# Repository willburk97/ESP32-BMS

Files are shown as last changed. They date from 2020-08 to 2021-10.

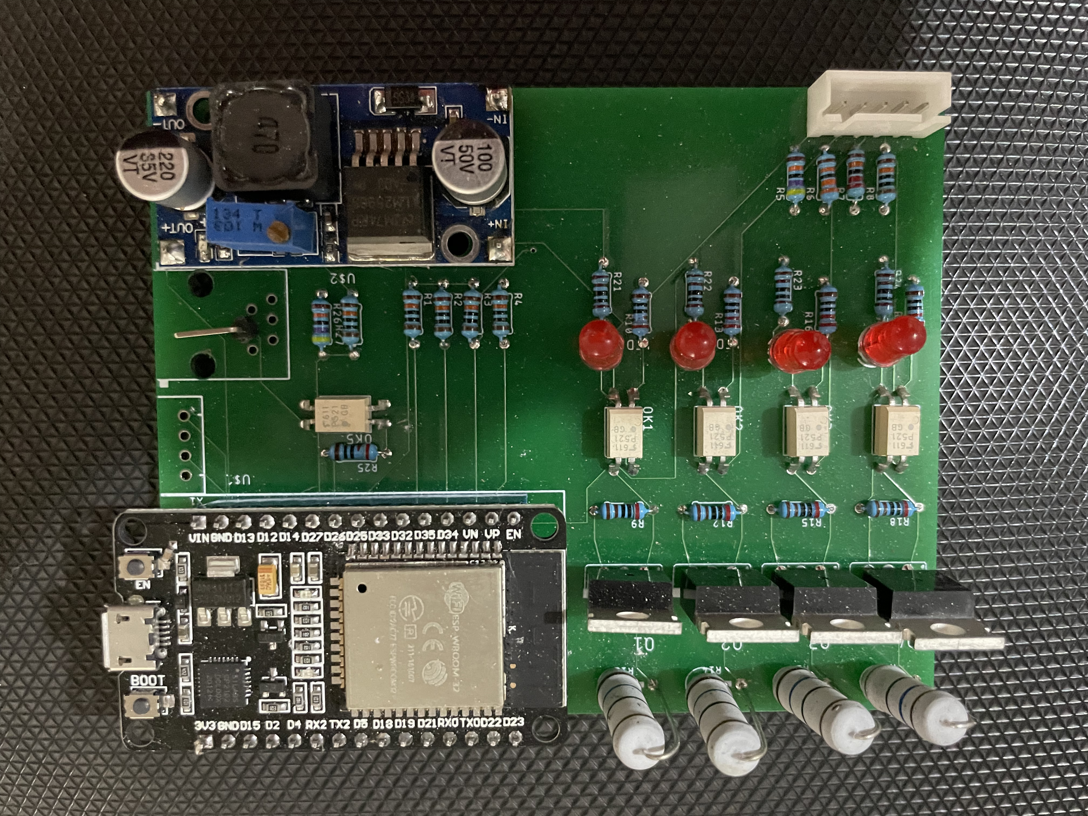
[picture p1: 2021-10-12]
7137F148-6C9B-44C9-9018-F6575CC51281.jpeg

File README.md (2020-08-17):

# ESP32-BMS
Single ESP32 monitoring and balancing multiple cell Li-Ion battery.

For each cell, to enable discharging, the ESP32 drives an opto-coupler (P521) with the digital output and the opto-coupler is driving the discharge mosfet(IRFZ44N) /resistor(16ohm,3W) across each cell. This'll be duplicatable across any number of cells (given the ESP32 has enough analog inputs and digital outputs. I'm using it for a 4 cell BMS/monitor which is using Adafruit io for trending/remote monitoring. The RJ11 port is to connect it to an Inverter. This is NOW coded in. I wasn't able to test the newer design with my old Kisae Inverter but the circuit in my original BMS worked fine (The single Arduino with a ESP8266-01 BMS).  

Note:  I added an I2C port to easily allow for adding components (like maybe an LCD/OLED display).

Ordered PCB and succesfully tested it (before I added the mounting holes and the wider traces.)   Worked great (didn't test i2c or rj11 port.)

My Kisae SW1220 inverter died in a lightning strike, but if you have one I think the schematic/board need to be changed to have Battery+ going to the optocoupler and the other leg going to the RJ11 port. (The wires on the opto-coupler will have to be reversed of course.)

My replacement inverter, a Go-Power GP-SW2000-12, has a remote input (Gnd, Enab, !Enab). I was able to use the schematic/board as is and simply connect the !Enab input on the inverter directly to the opto-coupler connection at the RJ11 port. (Which gets grounded when the digital output from the ESP32 turns on.)

Note: The Kisae inverter used a momentary Battery+ signal to turn the inverter on or off (change it from one state to the other).  The Go Power inverter requires a constant input signal (either battery+ or Gnd depending on the input you use) in order to be powered on. (Enab requires Batt+, !Enab requires Gnd, pick one to use.) The current code works with the Go Power Inverter.

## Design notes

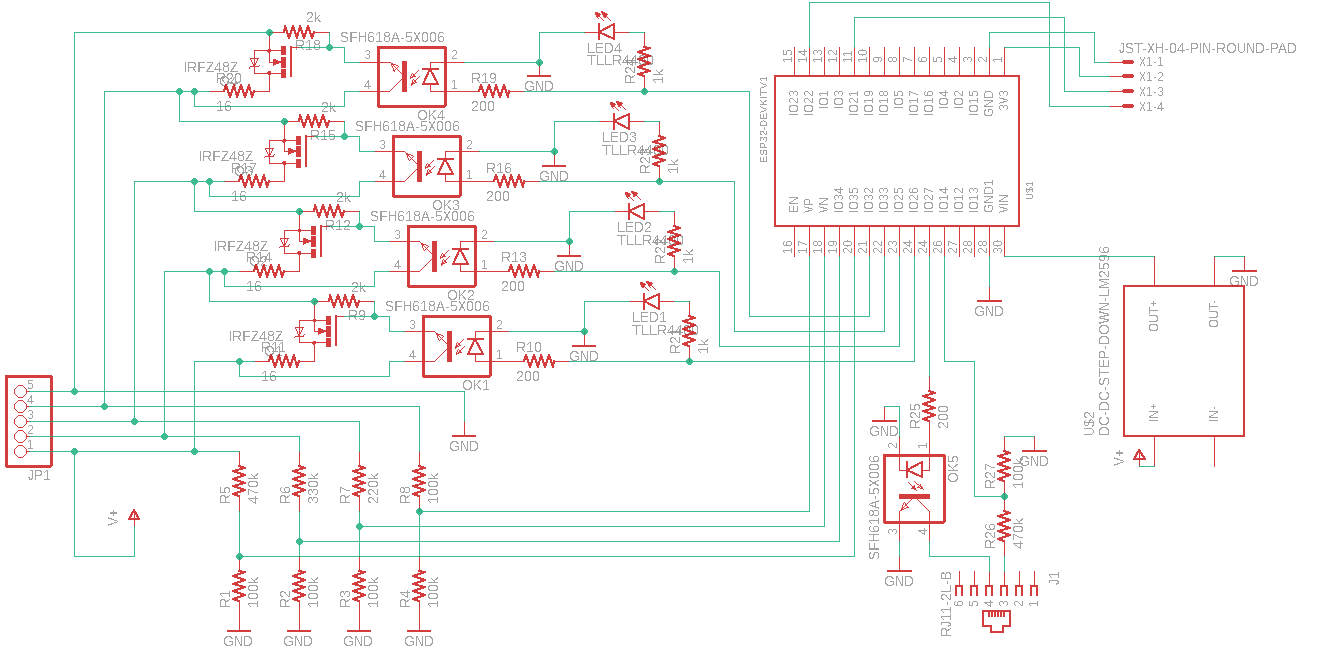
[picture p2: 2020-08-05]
FinalSchematic.png

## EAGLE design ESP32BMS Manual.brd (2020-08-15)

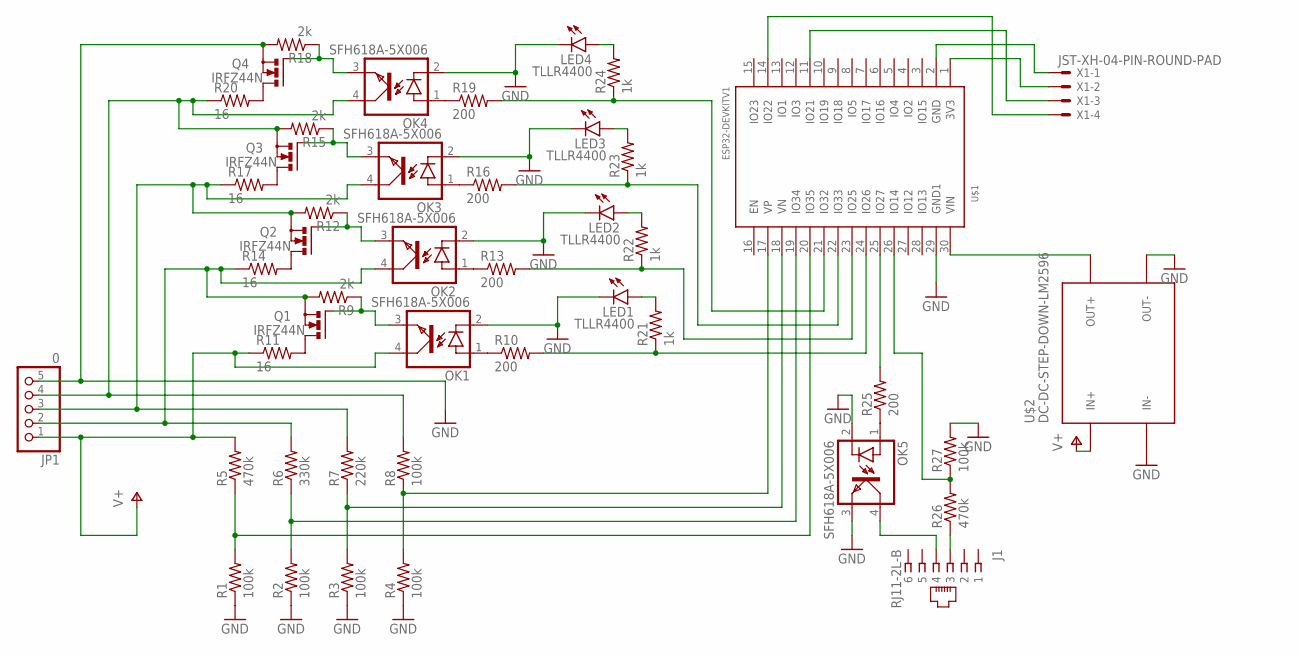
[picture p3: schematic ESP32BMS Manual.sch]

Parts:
J1: RJ11-2L-B; RJ11-NO_SHIELD
JP1: 0; 1X05
LED1, LED2, LED3, LED4: TLLR4400; LED3MM
OK1, OK2, OK3, OK4, OK5: SFH618A-5X006; DIP4-400
Q1, Q2, Q3, Q4: IRFZ44N; TO220BV
R1, R2, R3, R4, R8, R27: 100k; 0204/7
R5, R26: 470k; 0204/7
R6: 330k; 0204/7
R7: 220k; 0204/7
R9, R12, R15, R18: 2k; 0204/7
R10, R13, R16, R19, R25: 200; 0204/7
R11, R14, R17, R20: 16; 0414V
R21, R22, R23, R24: 1k; 0204/7
U$1: ESP32DEVKITV1; ESP32-DEVKITV1
U$2: DC-DC-STEP-DOWN-LM2596
X1: JST-XH-04-PIN-ROUND-PAD; JST-XH-04-PACKAGE-ROUND-PAD

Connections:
GND: JP1.5, LED1.K (C), LED2.K (C), LED3.K (C), LED4.K (C), OK1.2 (C), OK2.2 (C), OK3.2 (C), OK4.2 (C), OK5.2 (C), OK5.3 (EMIT), Q4.S, R1.1, R2.1, R3.1, R4.1, R18.2, R27.2, U$1.29 (GND1), U$2.IN-, U$2.OUT-
unnamed: R4.2, R8.1, U$1.17 (VP)
unnamed: R3.2, R7.1, U$1.18 (VN)
unnamed: R2.2, R6.1, U$1.19 (IO34)
unnamed: R1.2, R5.1, U$1.20 (IO35)
unnamed: LED1.A, R21.2
unnamed: JP1.2, OK2.4 (COL), Q1.S, R6.2, R9.2, R14.1
unnamed: JP1.3, OK3.4 (COL), Q2.S, R7.2, R12.2, R17.1
unnamed: JP1.4, OK4.4 (COL), Q3.S, R8.2, R15.2, R20.1
unnamed: OK1.1 (A), R10.1
unnamed: R19.2, R24.1, U$1.21 (IO32)
unnamed: OK2.1 (A), R13.1
unnamed: R16.2, R23.1, U$1.22 (IO33)
unnamed: R13.2, R22.1, U$1.23 (IO25)
unnamed: Q1.D, R11.2
unnamed: OK1.3 (EMIT), Q1.G, R9.1
unnamed: R10.2, R21.1, U$1.24 (IO26)
unnamed: Q2.D, R14.2
unnamed: OK2.3 (EMIT), Q2.G, R12.1
unnamed: U$1.30 (VIN), U$2.OUT+
unnamed: OK3.1 (A), R16.1
unnamed: LED2.A, R22.2
unnamed: Q3.D, R17.2
unnamed: OK3.3 (EMIT), Q3.G, R15.1
unnamed: LED3.A, R23.2
unnamed: OK4.1 (A), R19.1
unnamed: LED4.A, R24.2
unnamed: Q4.D, R20.2
unnamed: OK4.3 (EMIT), Q4.G, R18.1
unnamed: OK5.1 (A), R25.1
unnamed: R26.2, R27.1, U$1.26 (IO14)
unnamed: R25.2, U$1.25 (IO27)
unnamed: J1.3, R26.1
unnamed: J1.4, OK5.4 (COL)
unnamed: U$1.1 (3V3), X1.2
unnamed: U$1.2 (GND), X1.1
unnamed: U$1.11 (IO21), X1.3
unnamed: U$1.14 (IO22), X1.4
V+: JP1.1, OK1.4 (COL), R5.2, R11.1, U$2.IN+

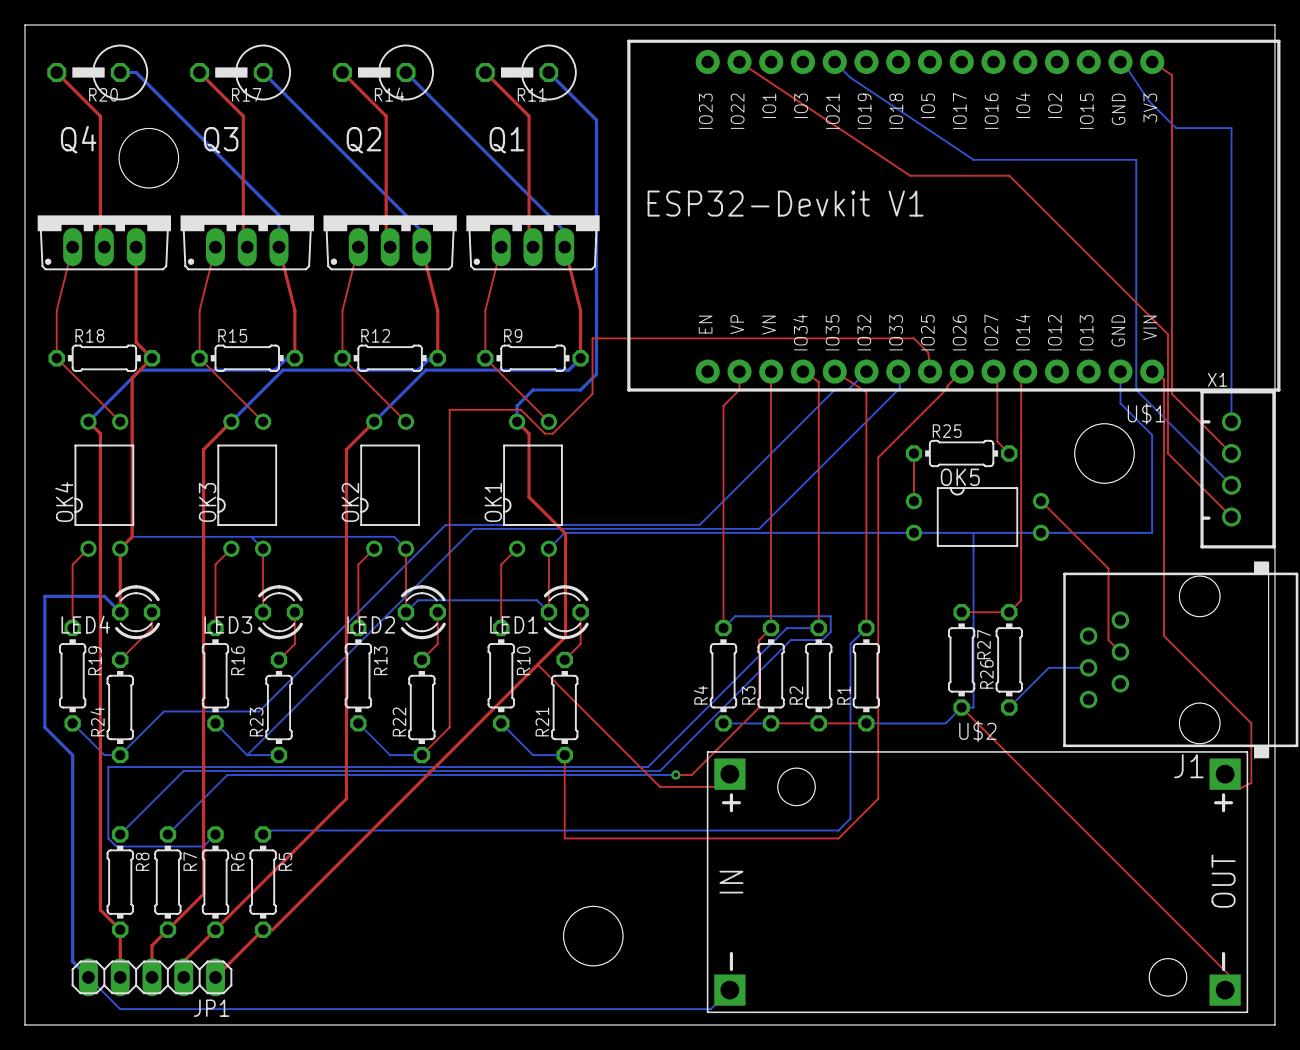
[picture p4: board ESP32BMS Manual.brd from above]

Board: 2 copper layers, 100.0 x 80.0 mm, 45 parts (0 on the bottom side), 39 nets.

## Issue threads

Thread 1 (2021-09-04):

Please include a screenshot of the board for people without PCB layout software installed

shodanx2, 2021-09-04:
It would explain a lot about how this works.

shodanx2, 2021-10-13:
These images should be easy to navigate to from the landing page (so readme file in your case)
They should specify which hardware version is depicted. Give them a version number even if they are the "final" version

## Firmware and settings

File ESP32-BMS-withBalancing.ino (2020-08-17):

// Tutorial Link: https://learn.adafruit.com/adafruit-io-basics-analog-input
//
// Adafruit invests time and resources providing this open source code.
// Please support Adafruit and open source hardware by purchasing
// products from Adafruit!
//
// Some written by Todd Treece for Adafruit Industries
// The rest written by William Burk for himself.
// Sorry Todd, for the mess.
// Copyright (c) 2016 Adafruit Industries
// Licensed under the MIT license.
//
// All text above must be included in any redistribution.


#define IO_USERNAME "NukeHunter"
#define IO_KEY "yourkeyhere"
#define WIFI_SSID "yourssidhere"
#define WIFI_PASS "yourpasswordhere"
#include "AdafruitIO_WiFi.h"
AdafruitIO_WiFi io(IO_USERNAME, IO_KEY, WIFI_SSID, WIFI_PASS);

#define LEDPin 2
#define inverterPin 27
int cell = 0;
int analogIn[] = {36, 39, 34, 35};
int dischargePin[] = {32, 33, 25, 26};
bool dischargeState[] = {false, false, false, false}; 
unsigned int sensorInt;
float sensorValue = 0;
float allowedCellDiff = 0.04;  /// 0.02 for big pack?
float lowBatt = 10;
unsigned long lastTxTime = 0;
unsigned int minTxTime = 60000;
//unsigned int sampleTime = 1000;
String debugText = "0.00 0.00 0.00 0.00 ";
//unsigned int dischargeTime[] = {0, 0, 0, 0};
int i;
float battVolt[4];
float cellVolt[4];
// bool inverterControl = false;  // not used yet

AdafruitIO_Feed *espbattery = io.feed("espbattery");
AdafruitIO_Feed *espbattery2 = io.feed("espbattery2");
AdafruitIO_Feed *espbattery3 = io.feed("espbattery3");
AdafruitIO_Feed *espbattery4 = io.feed("espbattery4");
//AdafruitIO_Feed *debugtext = io.feed("debug-text");
AdafruitIO_Feed *inverterstatus = io.feed("inverterstatus");
AdafruitIO_Feed *battdischarge1 = io.feed("battdischarge1");
AdafruitIO_Feed *battdischarge2 = io.feed("battdischarge2");
AdafruitIO_Feed *battdischarge3 = io.feed("battdischarge3");
AdafruitIO_Feed *battdischarge4 = io.feed("battdischarge4");
//AdafruitIO_Feed *battdischargetime4 = io.feed("battdischargetime4");
AdafruitIO_Feed *packvoltage = io.feed("packvoltage");

void setup() {
  pinMode(inverterPin, OUTPUT);
  pinMode(LEDPin, OUTPUT);
  analogSetClockDiv(20);
  for (cell=1;cell<5;cell++) {
    pinMode(dischargePin[cell-1], OUTPUT);
  }

  for (i=0;i<50;i=i+1) { analogRead(analogIn[1-1]); }  // Prevent first couple of reads from being anomalous.

  Serial.begin(115200);

  Serial.print("Connecting to Adafruit IO");
  io.connect();   // connect to io.adafruit.com

  while(io.status() < AIO_CONNECTED) {    // wait for a connection
    Serial.print(".");
    delay(500);
  }

  // we are connected
  Serial.println();
  Serial.println(io.statusText());

  inverterstatus->onMessage(inverterStatusChange);
  inverterstatus->get();
}

void loop() {
  io.run();

  updateVoltage();

  //Check for over discharged cell.
  for (cell=1;cell<5;cell++) {
    if (cellVolt[cell-1] < 2.5) {
      digitalWrite(dischargePin[cell-1], false);
      dischargeState[cell-1] = false;
      digitalWrite(inverterPin, false);
      inverterstatus->save(false);
      Serial.print("Battery "); Serial.print(cell); Serial.println(" Forced draining off...and inverter forced off.");
    }
  }

  
  // Blink to show sampling
  digitalWrite(LEDPin, HIGH); delay(30); digitalWrite(LEDPin, LOW);

  
// Do this every minute

  if(millis() > lastTxTime + minTxTime)
  {
    lastTxTime = millis();

    digitalWrite(LEDPin, HIGH);  // Long blink means transmitting and checking (non-balancing voltage)
    
    // Turn off discharging circuits.
    for (cell=1;cell<5;cell++) { 
      digitalWrite(dischargePin[cell-1], false);
    }

    delay(500); // Give cells time to settle.

    updateVoltage();

    // Get Low Cell Voltage
    lowBatt = 10; for (i=0;i<4;i++) { if (cellVolt[i] < lowBatt) { lowBatt = cellVolt[i]; } }
    Serial.print("Low Batt is at ");Serial.println(lowBatt);

    if (lowBatt > 3.5) { digitalWrite(inverterPin,true); }  // If battery has some juice, turn on the inverter.
  
    // Check for balance and turn on/off balancers
    for (cell=1;cell<5;cell++) {
  
      if ((cellVolt[cell-1] > (lowBatt + allowedCellDiff)) && (cellVolt[cell-1] > 3.0)) {
        digitalWrite(dischargePin[cell-1], true);
        dischargeState[cell-1] = true;
        Serial.print("Battery ");Serial.print(cell);Serial.println(" Draining");
      }
      else {
        digitalWrite(dischargePin[cell-1], false);
        dischargeState[cell-1] = false;
        Serial.print("Battery ");Serial.print(cell);Serial.println(" Not Draining");
      }

//      if (dischargeState[cell-1]) { dischargeTime[cell-1]++; } // Track minutes of discharging.

    }

    
    updateAdafruit();  // Here so we have accurate voltages as well as discharge status.
    
    digitalWrite(LEDPin, LOW);

  }

  delay(200); //Adjust to keep sample time around 1 second.
}


void updateAdafruit() {
  Serial.println("Sending Data");

  espbattery->save(cellVolt[1-1]);
  espbattery2->save(cellVolt[2-1]);
  espbattery3->save(cellVolt[3-1]);
  espbattery4->save(cellVolt[4-1]);
  inverterstatus->save(digitalRead(inverterPin));
//  debugtext->save(debugText);
  battdischarge1->save(dischargeState[1-1]);
  battdischarge2->save(dischargeState[2-1]);
  battdischarge3->save(dischargeState[3-1]);
  battdischarge4->save(dischargeState[4-1]);
//  battdischargetime4->save(dischargeTime[4-1]);
  packvoltage->save(battVolt[4-1]);


  //    inverter->get();  Get inverter status someday?
}


void updateVoltage() {
  
  for (cell=1;cell<5;cell++) {
 
    sensorInt = 0;
    for (i=0;i<10;i++) { analogRead(analogIn[cell-1]); }
    for (i=0;i<100;i++) {
      delay(3);
      sensorInt = sensorInt + analogRead(analogIn[cell-1]);
    }

    sensorInt = sensorInt / 100;

    if (cell == 1) {sensorValue = (sensorInt * 2.193 * 3.3) / 4096;  }
    else if (cell == 2) {sensorValue = (sensorInt * 3.471 * 3.3) / 4096;  }
    else if (cell == 3) {sensorValue = (sensorInt * 4.452 * 3.3) / 4096;  }
    else {sensorValue = (sensorInt * 6.225 * 3.3) / 4096;  }
    
    sensorInt = (sensorValue * 100);     // Round to two decimal places...
    sensorValue = sensorInt;
    sensorValue = sensorValue / 100;

    battVolt[cell-1] = sensorValue;

    cellVolt[cell-1] = (battVolt[cell-1]-(battVolt[cell-1-1]*(cell!=1)));

  }

  
      debugText = "";
      for (i=0;i<4;i=i+1) {
        Serial.print(battVolt[i]); Serial.print(" ");
        debugText += String(battVolt[i]);
        debugText += String(" ");
      }
      Serial.println();
}



void inverterStatusChange(AdafruitIO_Data *data) {
//  inverterStatus = data->toInt();
Serial.print("Inverter: ");Serial.println(data->toPinLevel());
  digitalWrite(inverterPin,data->toPinLevel());
}

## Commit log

2020-07-30 Adding Schematics
    The mosfets and the optocouplers listed are not what I used (I couldn't find them in Eagle). I used an IRZF44N mosfet and P521 Opto-Coupler. The resistors values are correct but the part numbers are not. Most are just 1/4W resistors. The 16 ohm is a 3W resistor.
    [ESP32BMS.sch]
2020-07-30 Fixed polarity on batteries in schematics.
    [ESP32BMS.sch]
2020-08-15 Added mounting holes and widened discharge paths/traces.
    [ESP32BMS Manual.brd]
2020-08-17 Added Inverter Code
    Added Basic Inverter control code... My go-power sw2000-12 inverter has a remote input which is connected directly to the opto-coupler output (at the RJ11 port). Open = inverter off, grounded = inver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
2021-10-12 Add photo of functional board

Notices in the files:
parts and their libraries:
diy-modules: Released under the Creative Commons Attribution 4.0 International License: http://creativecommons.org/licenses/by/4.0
